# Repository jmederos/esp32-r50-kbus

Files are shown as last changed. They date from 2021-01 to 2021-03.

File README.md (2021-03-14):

# ESP32 K-bus Interface

[][license-url]
[][linkedin-url]

## Table of Contents

* [About the Project](#about)
  * [Hardware](#hardware)
  * [Software](#software)
* [Getting Started](#getting-started)
  * [Prerequisites](#prerequisites)
  * [Building](#building)
  * [Installing](#installing)
* [Roadmap](#roadmap)
* [License](#license)

## About

K-bus/I-bus to Bluetooth bridge for Mini/BMWs. Developed on esp-idf 4.0.2 and a 2006 Mini Cooper. Main goal was to get AVRCP control from steering wheel to iPhone; going forward looking to make it a platform for emulating K-bus devices.

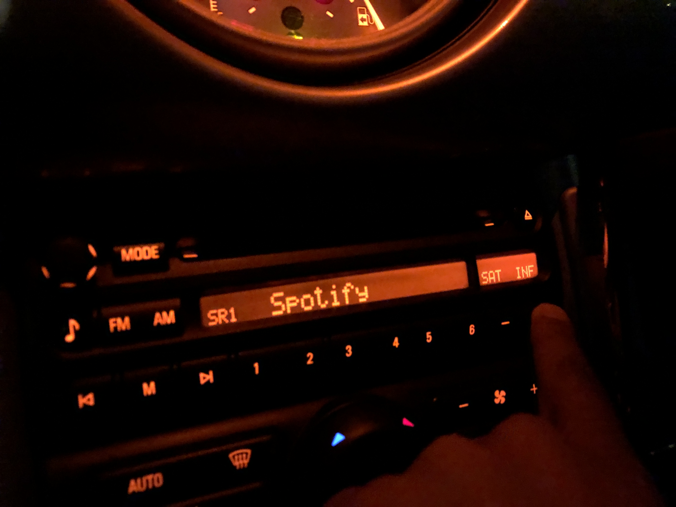
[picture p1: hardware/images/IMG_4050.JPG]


### Hardware

See [hardware](hardware) folder

### Software

* [esp-idf](https://github.com/espressif/esp-idf)
* [btstack](https://github.com/bluekitchen/btstack)

<!-- GETTING STARTED -->
## Getting Started

Clone, build, and flash.

### Prerequisites

Install `esp-idf` and the ESP32 `btstack` port by following the respective instructions.

### Building

#### Hardware

**TBD**

#### Software

* Clone this repo and its submodules `git clone --recursive https://github.com/jmederos/esp32-r50-kbus.git`
* After installing prequisites, run the helper script `./tools/build.sh` to compile
* `./tools/flash_monitor.sh` to load onto ESP32 and run `idf.py monitor`
_Note: Helper scripts in tools folder assume a WSL Ubuntu install w/ESP32 on Windows COM4_

### Installing

* Use OEM CD changer pre-wiring in R50 behind right side panel in trunk.

#### R50 Support Docs
* [How to find pre-wiring](https://www.northamericanmotoring.com/forums/navigation-and-audio/224408-can-t-find-cd-changer-pre-wiring.html)
* [CD changer installation instructions](https://new.minimania.com/images/instructions/OEM%20CD%20Changer.pdf)

## Roadmap
| Feature | Status | Notes |
| --- | --- | --- |
| Software POC: control phone via AVRCP w/o A2DP advertised. | 👌🏽 | _Although part of the BT spec, example implementations on AVRCP-only are hard to come by._ |
| Hardware POC: acquire + test k-line transceivers. | 🙌🏽 | |
| K-bus proof concept, pickup MFL messages. | 👍🏽 | _Works in vehicle, works in mockup w/Navcoder + iPhone streaming to a BT headphone amp._ |
| Write to radio head unit display | 🥳 | _Seems to work, now let's do scrolling display_ |
| SDRS Emulation | 👍🏽 | _Functional, didn't really like the fact that FiiO BT amp didn't shutdown with car; will stick to aux input + `TEL` display updates for now._ |
| Write to radio head unit display | 🥳 | _Seems to work, now let's do scrolling display_ |
| [AMS](https://developer.apple.com/library/archive/documentation/CoreBluetooth/Reference/AppleMediaService_Reference/Specification/Specification.html) instead of AVRCP | | _Didn't know this was a thing, seems like a better bet; btstack + esp-idf is a little clunky._ |
| [ANCS](https://developer.apple.com/library/archive/documentation/CoreBluetooth/Reference/AppleNotificationCenterServiceSpecification/Introduction/Introduction.html) Support & update radio display w/push notification | 🤞 | |

_See the [open issues](https://github.com/jmederos/esp32-r50-kbus/issues) for a list of proposed features (and known issues)._

## References
* [iPod ↔ Sirius IBus adapter](https://github.com/blalor/iPod_IBus_adapter) - _Referenced for SDRS packet logs (my car isn't equiped with one.)_
* [Hack The IBus](http://web.archive.org/web/20110320205413/http://ibus.stuge.se/Main_Page)

## License

Distributed under the MPL 2.0 License. See `LICENSE` for more information.

<!-- MARKDOWN LINKS & IMAGES -->
<!-- https://www.markdownguide.org/basic-syntax/#reference-style-links -->
[license-shield]: https://img.shields.io/badge/license-MPL%202.0-blue
[license-url]: https://github.com/jmederos/esp32-r50-kbus/blob/master/LICENSE
[linkedin-shield]: https://img.shields.io/badge/-LinkedIn-black.svg?style=flat-square&logo=linkedin&colorB=555
[linkedin-url]: https://linkedin.com/in/jacobmederos

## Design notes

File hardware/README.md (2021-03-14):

# Hardware

## Microcontroller
* [Sparkfun MicroMod ESP32](https://www.sparkfun.com/products/16781)
* [Sparkfun MicroMod ATP Board](https://www.sparkfun.com/products/16885)

## Power Regulation
| Part | Notes |
| --- | --- |
| ~~[On Semi NCV7805BTG 5V Regulator](https://www.digikey.com/en/products/detail/on-semiconductor/921437)~~ | Too inefficient
| [USB Power Supply](https://www.amazon.com/gp/product/B07KWRH61D) | Worked well for prototyping w/MicroMod ESP32
| [OKI-78SR-5](https://www.digikey.com/en/products/detail/OKI-78SR-5-1-5-W36H-C/3438675) | For v1 of feather board

## Transciever ICs
| Part | Status | Notes |
| --- | --- | --- |
| [ON Semi NCV7428D13R2G](https://www.digikey.com/en/products/detail/on-semiconductor/5022588) | 🤷🏽‍♂️ | Have it; still untested. |
| [NXP TJA1021T](https://www.digikey.com/en/products/detail/nxp-usa-inc/2034448) | 👍🏽 | Using with a `CP2102` USB ⇄ Serial to interface with NavCoder and simulate bus on desktop. |
| [TI SN65HVDA195QDRQ1](https://www.digikey.com/en/products/detail/texas-instruments/2094636) | 👎🏽 | Used on initial in-car perfboard prototypes. Works ok, but susceptible to glitching the bus (doors randomly unlocked); doesn't have tx timeout or contention detection. Best used to create a simulated bus as the controlling node like the `NXP` part above. |
| [Microchip MCP2025](https://www.digikey.com/en/products/detail/microchip-technology/3543134) | 🤷🏽‍♂️ | Have it; unlikely to test/use it. Doesn't have failsafe features and isn't pin-compatible w/`TI` |
| [Microchip MCP2004(A)](https://www.digikey.com/en/products/detail/MCP2004AT-E-SN/2803651) | 👍🏽 | Selected for tx timeout and bus contention detection + added bonus of `FAULT` pin. Also pin compatible with `TI` and `NXP` parts used for prototyping. So far, only tested `MCP2004A`; works in simulated bus setup. |
| [Microchip MCP2003B](https://www.digikey.com/en/products/detail/this-gets-ignored-🤷🏽‍♂️/5810590) | 🤷🏽‍♂️ | Selected for tx timeout and bus contention detection. Also pin compatible with `TI` and `NXP` parts used for prototyping. Have it; still untested. |

## Connector
The CD Changer connectors are a 3-pin power/data (all populated) and 6-pin audio (3 or 4 populated)
| Part | Notes |
| --- | --- |
| [TE AMP 1-1718346-1](https://www.newark.com/these/doNot/matter/dp/86Y2196) | Existing pre-wiring connector supplying `gnd`, `12v`, `kbus` |
| [TE AMP 1-968700-1](https://www.newark.com/these/doNot/matter/dp/86Y4923) | Matching socket for above; a row of 3 pin headers can also be used if this can't be sourced. OEM part [BMW 61 13 6 931 929](https://www.ecstuning.com/b-genuine-bmw-parts/pin-terminal/61136931929/) is order of magnitude more expensive. |
| [TE AMP 1379118-1](https://www.newark.com/these/doNot/matter/dp/69AH9772) | Matching socket for 6-pin audio connector. Depending on vehicle either 3 pin unbalanced audio or 4 pin balanced audio. |

## Board
Created a simple board for a more permanent installation

### BOM
_TODO_

### Pictures
<p>
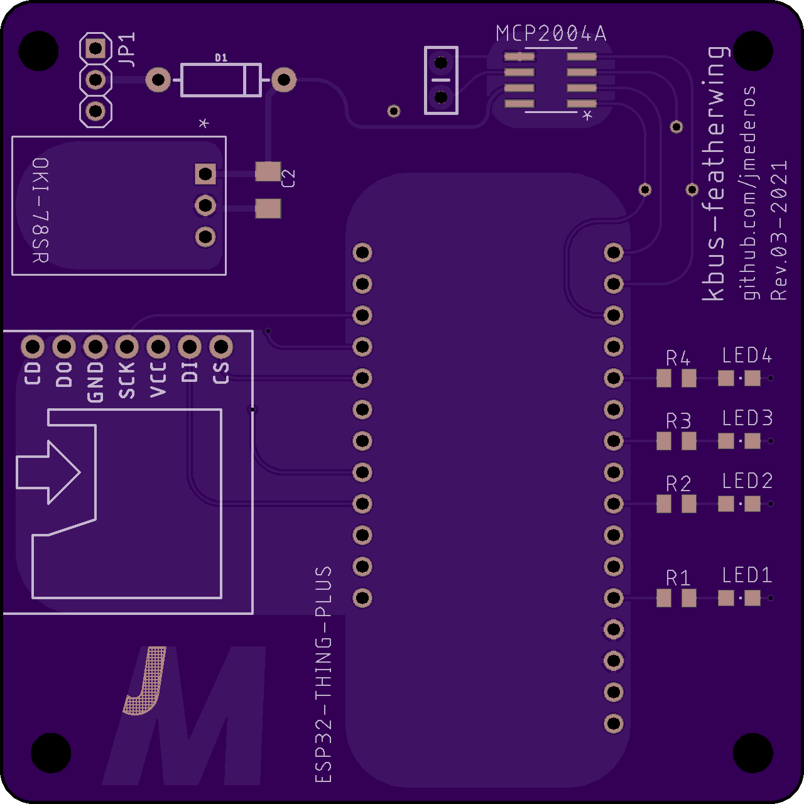
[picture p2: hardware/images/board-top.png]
  
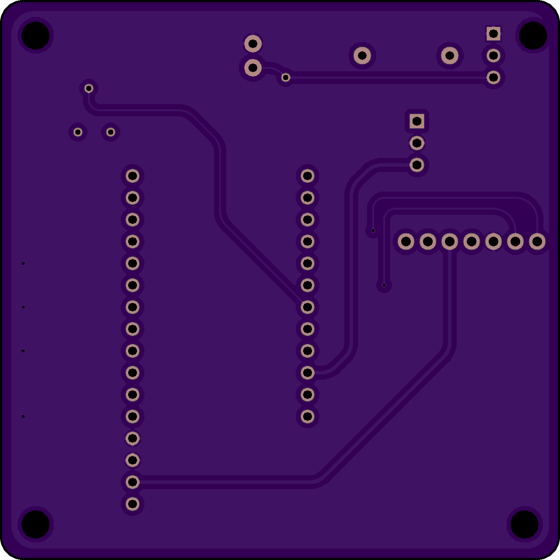
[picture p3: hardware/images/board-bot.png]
  
</p>
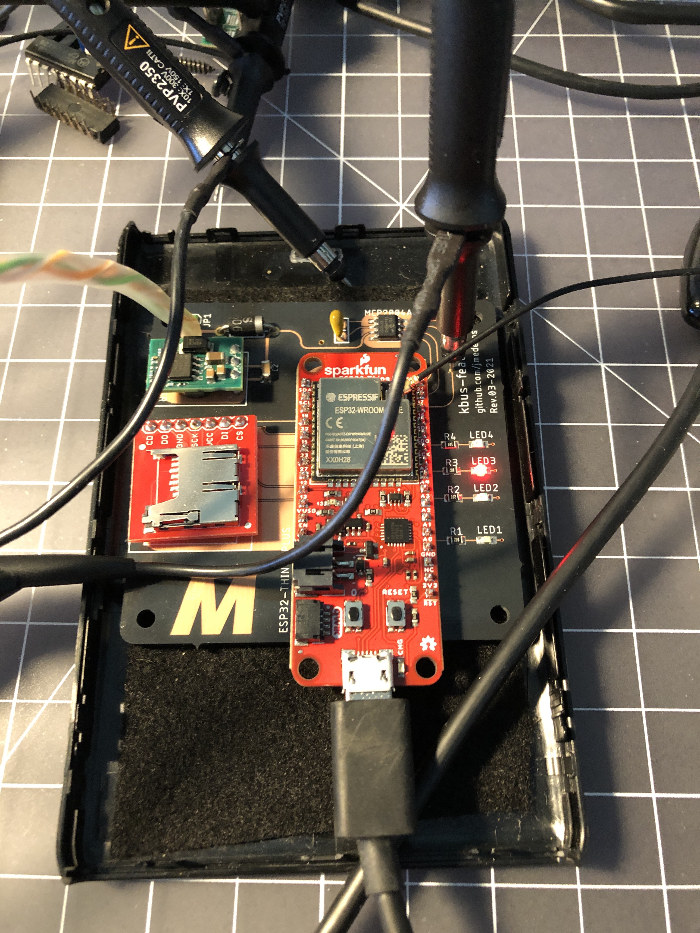
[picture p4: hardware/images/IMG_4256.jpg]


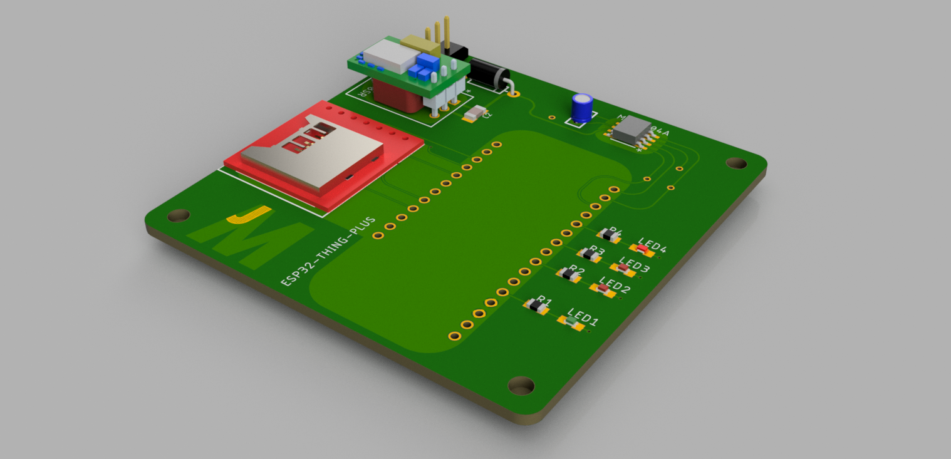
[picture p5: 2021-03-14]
hardware/images/thing-plus-carrier v12.PNG

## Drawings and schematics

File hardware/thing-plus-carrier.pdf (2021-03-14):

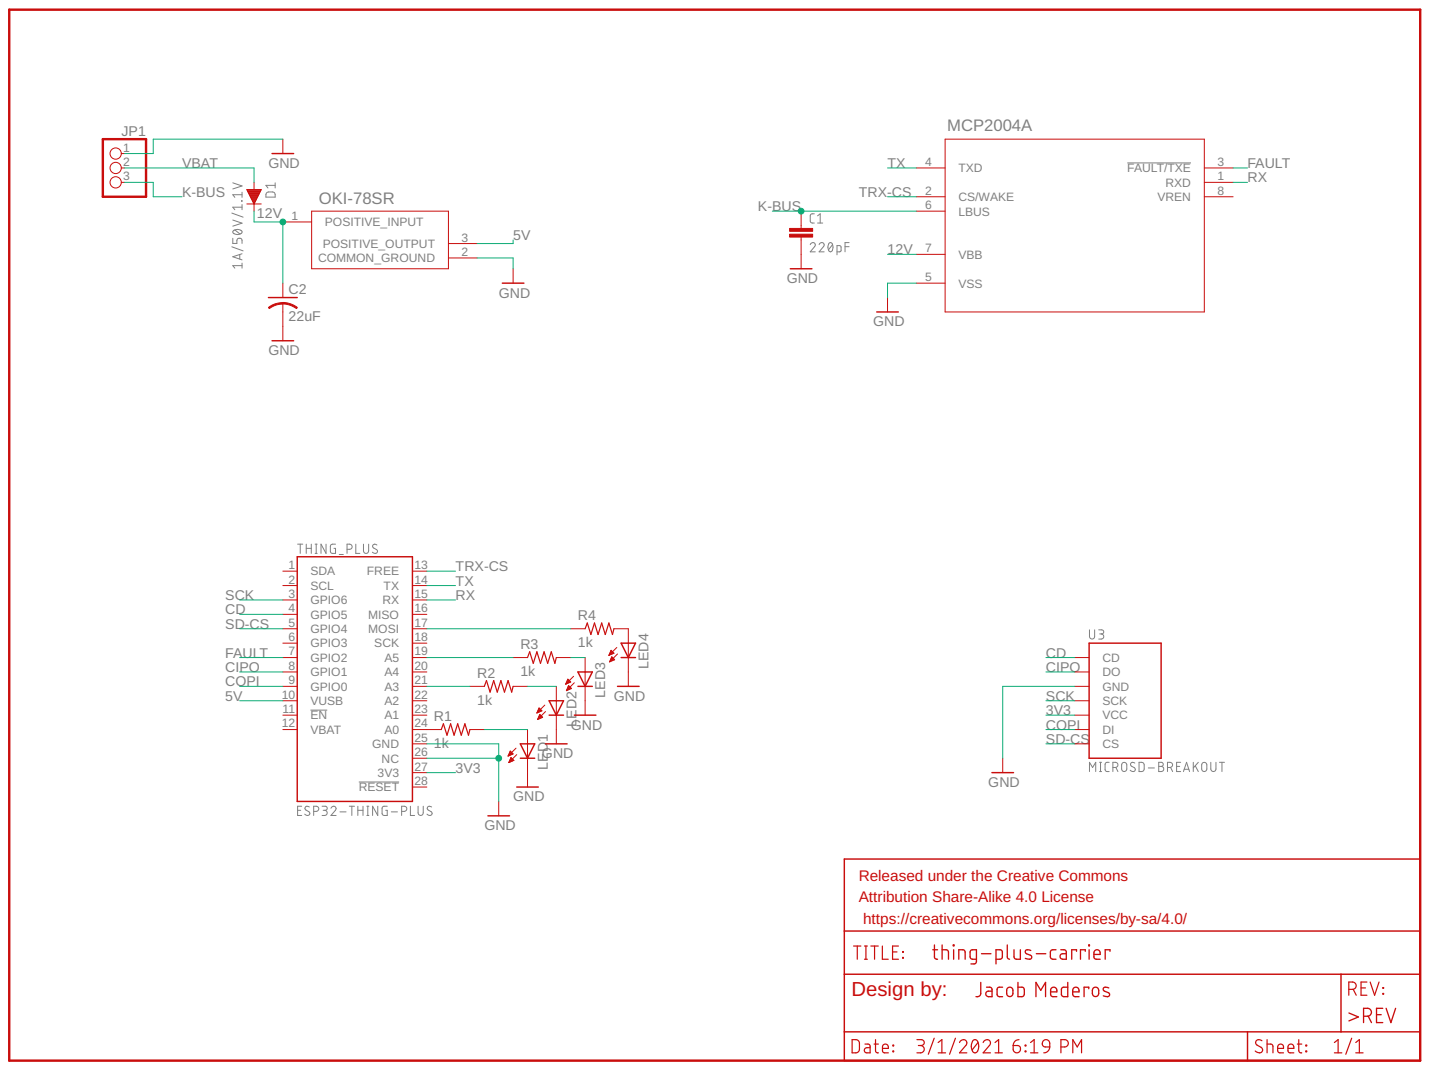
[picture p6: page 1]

Released under the Creative Commons Attribution Share-Alike 4.0 License

https://creativecommons.org/licenses/by-sa/4.0/

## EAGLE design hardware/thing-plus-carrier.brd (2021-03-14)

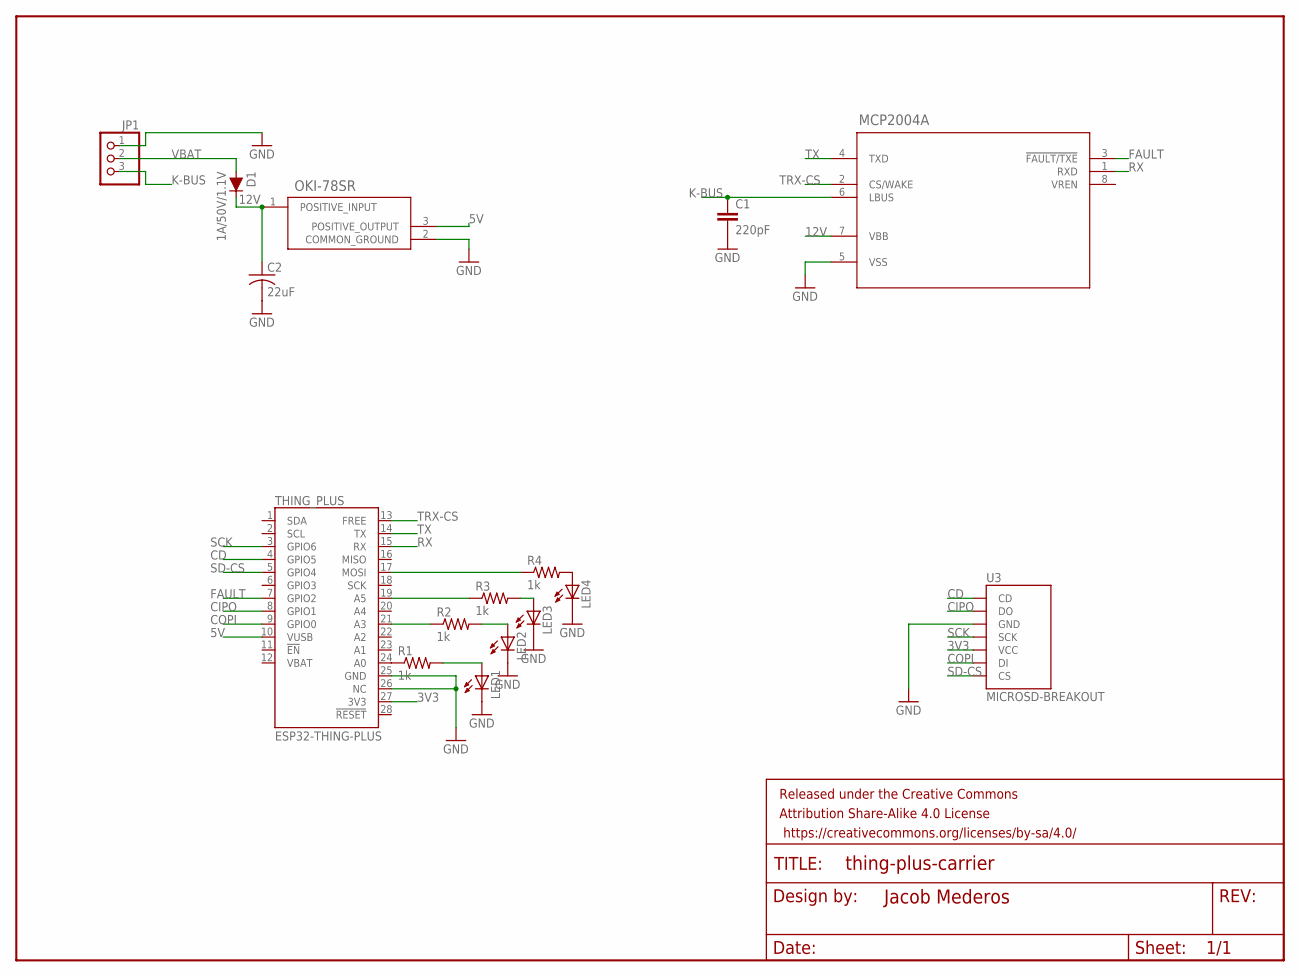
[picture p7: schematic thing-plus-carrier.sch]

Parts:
C1: 220pF; CAP-PTH-SMALL-KIT
C2: 22uF; C1206K
D1: 1A/50V/1.1V; DIODE-1N4001
ESP32-THING-PLUS: THING_PLUS
FRAME1: FRAME-LETTERNO_PACKAGE; DUMMY
JP1: PINHD-1X3; 1X03
LED1, LED2, LED3, LED4: LEDCHIPLED_0805; CHIPLED_0805
MCP2004A: MCP2004A-E/SNSOIC8_4P9X3P9MC_MCH-M; SOIC8_4P9X3P9MC_MCH-M
OKI-78SR: OKI-78SR-5/1.5-W36H-C; OKI-78SR-5/1.5-W36H-C_MUR
R1, R2, R3, R4: 1k; R0805
U3: MICROSD-BREAKOUT

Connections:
3V3: ESP32-THING-PLUS.27 (3V3), U3.VCC
5V: ESP32-THING-PLUS.10 (VUSB), OKI-78SR.3 (POSITIVE_OUTPUT)
12V: C2.1, D1.C, MCP2004A.7 (VBB), OKI-78SR.1 (POSITIVE_INPUT)
CD: ESP32-THING-PLUS.4 (GPIO5), U3.CD
CIPO: ESP32-THING-PLUS.8 (GPIO1), U3.DO
COPI: ESP32-THING-PLUS.9 (GPIO0), U3.DI
FAULT: ESP32-THING-PLUS.7 (GPIO2), MCP2004A.3 (!FAULT/TXE)
GND: C1.2, C2.2, ESP32-THING-PLUS.25 (GND), ESP32-THING-PLUS.26 (NC), JP1.1, LED1.C, LED2.C, LED3.C, LED4.C, MCP2004A.5 (VSS), OKI-78SR.2 (COMMON_GROUND), U3.GND
K-BUS: C1.1, JP1.3, MCP2004A.6 (LBUS)
unnamed: ESP32-THING-PLUS.19 (A5), R3.1
unnamed: ESP32-THING-PLUS.24 (A0), R1.1
unnamed: ESP32-THING-PLUS.21 (A3), R2.1
unnamed: ESP32-THING-PLUS.17 (MOSI), R4.1
unnamed: LED4.A, R4.2
unnamed: LED3.A, R3.2
unnamed: LED2.A, R2.2
unnamed: LED1.A, R1.2
RX: ESP32-THING-PLUS.15 (RX), MCP2004A.1 (RXD)
SCK: ESP32-THING-PLUS.3 (GPIO6), U3.SCK
SD-CS: ESP32-THING-PLUS.5 (GPIO4), U3.CS
TRX-CS: ESP32-THING-PLUS.13 (FREE), MCP2004A.2 (CS/WAKE)
TX: ESP32-THING-PLUS.14 (TX), MCP2004A.4 (TXD)
VBAT: D1.A, JP1.2

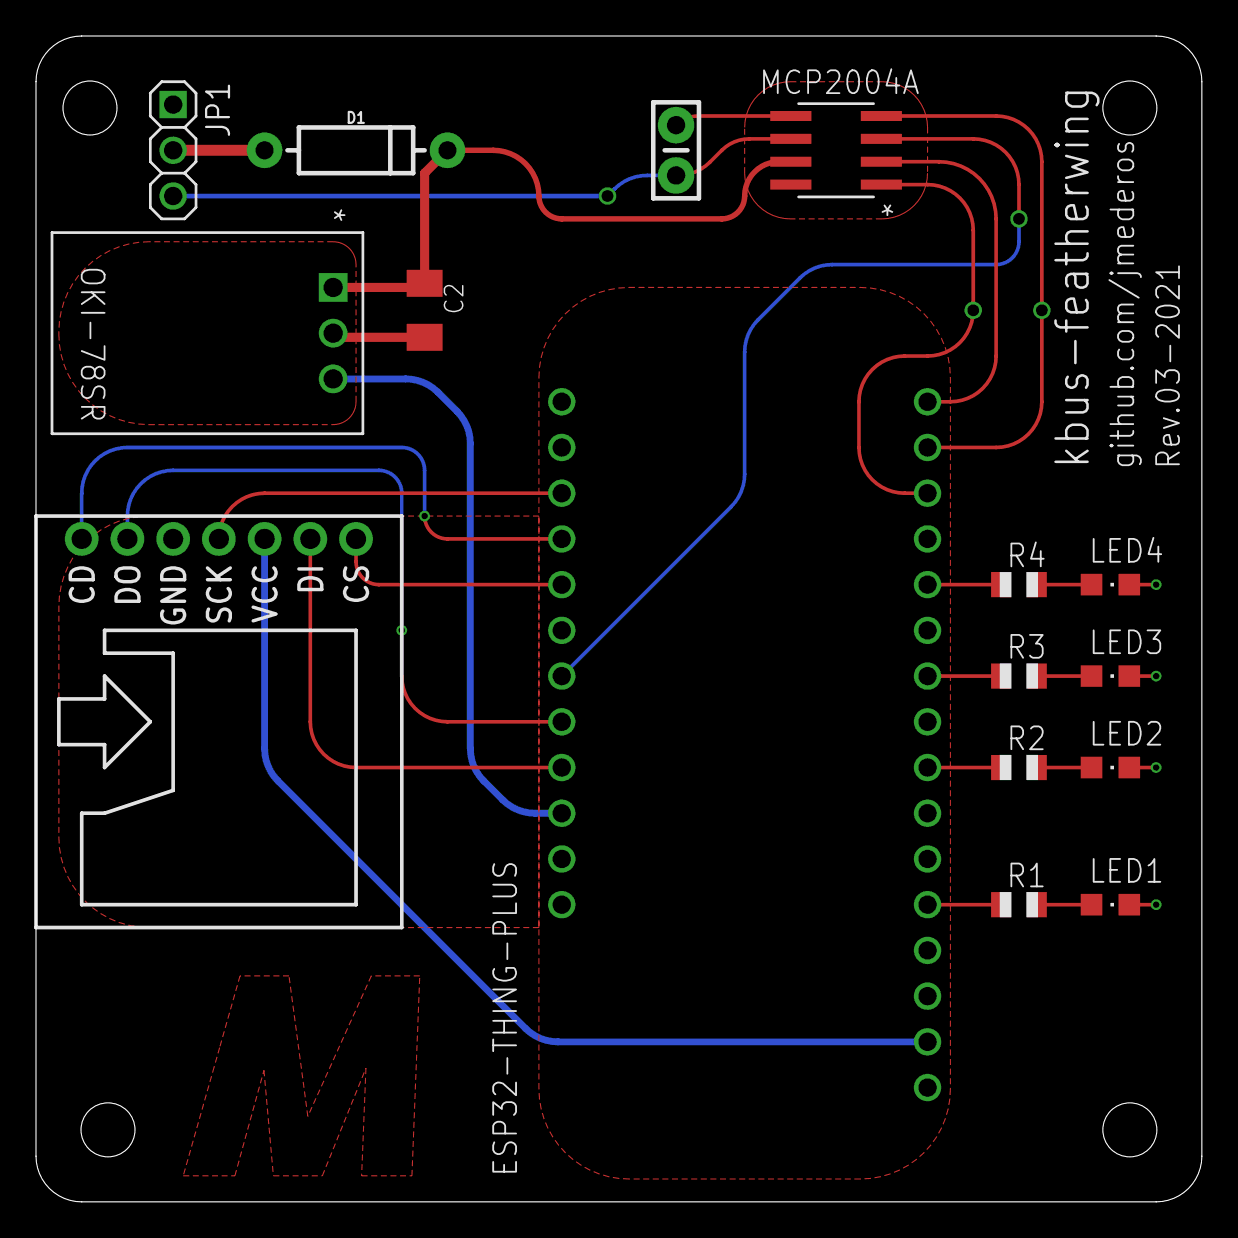
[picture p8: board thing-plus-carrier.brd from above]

Board: 2 copper layers, 64.8 x 64.8 mm, 17 parts (0 on the bottom side), 23 nets.

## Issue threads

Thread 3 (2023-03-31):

ninja: error: 'C:/Users/mhipik/Desktop/PROJEKT BMW/esp32-r50-kbus/html', needed by 'esp-idf/espfs/espfs_image.bin',

marttin-h, 2023-03-31:
hi, I get this error when I run the command idf.py -p COM6 flash
Executing "ninja flash"...
ninja: error: 'C:/Users/user01/Desktop/esp32-r50-kbus/html', needed by 'esp-idf/espfs/espfs_image.bin', missing and no known rule to make it
ninja failed with exit code 1, output of the command is in the ....

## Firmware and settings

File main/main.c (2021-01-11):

// C stdlib includes
#include <stddef.h>
#include <stdio.h>

// FreeRTOS includes
#include "freertos/FreeRTOS.h"
#include "freertos/projdefs.h"
#include "freertos/queue.h"
#include "freertos/task.h"

// esp-idf includes
#include "esp_system.h"
#include "esp_log.h"
#include "nvs_flash.h"

// btstack includes
#include "btstack_port_esp32.h"
#include "btstack_run_loop.h"
#include "hci_dump.h"

// component includes
#include "bt_services.h"
#include "wifi_service.h"
#include "kbus_service.h"
#include "bt_common.h"

#define SECONDS(sec) ((sec*1000) / portTICK_RATE_MS)

// TODO: Add these as menuconfig items
#define R50_BT_ENABLED
// #define R50_WIFI_ENABLED

// ! Debug Flags
// #define TASK_DEBUG

static const char* TAG = "r50-main";
static QueueHandle_t bt_cmd_queue, bt_info_queue;

#ifdef TASK_DEBUG
static void watcher_task(){
    const size_t bytes_per_task = 40;
    char *task_list_buffer = NULL;
    vTaskDelay(SECONDS(5));

    while(1){
        task_list_buffer = (char*) malloc(uxTaskGetNumberOfTasks() * bytes_per_task);
        if (task_list_buffer == NULL) {
            ESP_LOGE(TAG, "failed to allocate buffer for vTaskList output");
            abort();
        }

        vTaskList(task_list_buffer);
        printf("\n%sTask\t\tStat\tPrity\tHWM\tTsk#\tCPU%s\n", "\033[1m\033[4m\033[44;1m\033[K", LOG_RESET_COLOR);
        printf("%s", task_list_buffer);

        vTaskGetRunTimeStats(task_list_buffer);
        printf("%sTask\t\tAbs Time\t\tUsage%%%s\n", "\033[1m\033[4m\033[42m\033[K", LOG_RESET_COLOR);
        printf("%s", task_list_buffer);

        free(task_list_buffer);
        vTaskDelay(SECONDS(120));
    }
}

static void create_watcher_task(){
    int task_ret = xTaskCreate(watcher_task, "task_watcher", 4096, NULL, 5, NULL);
    if(task_ret != pdPASS){ESP_LOGE(TAG, "task_watcher creation failed with: %d", task_ret);}
}
#endif

static void initNVS(){
    //Initialize NVS
    esp_err_t ret = nvs_flash_init();
    if (ret == ESP_ERR_NVS_NO_FREE_PAGES || ret == ESP_ERR_NVS_NEW_VERSION_FOUND) {
      ESP_ERROR_CHECK(nvs_flash_erase());
      ret = nvs_flash_init();
    }
    ESP_ERROR_CHECK(ret);
}

int app_main(void){
    initNVS();

#ifdef TASK_DEBUG
    ESP_LOGI(TAG, "Creating Task Watcher");
    create_watcher_task();
#endif

    // Setup bluetooth command queue
    bt_cmd_queue = xQueueCreate(4, sizeof(bt_cmd_type_t));
    // Setup bluetooth "now playing" queue
    bt_info_queue = xQueueCreate(2, sizeof(bt_now_playing_info_t));

    // Setup kbus service; has side-effect of initializing and starting UART driver.
    init_kbus_service(bt_cmd_queue, bt_info_queue);

#ifdef R50_WIFI_ENABLED // Gating wifi and bt since there's still issues with them running concurrently.
    wifi_init_softap();
#endif

#ifdef R50_BT_ENABLED
    ESP_LOGI(TAG, "Starting bt services...");
    bluetooth_services_setup(bt_cmd_queue, bt_info_queue);
    // Running btstack_run_loop_execute() as it's own task or in a wrapper wasn't working;
    // however, does work as lowest priority loop after other tasks. Going with this.
    ESP_LOGI(TAG, "btstack run loop");
    btstack_run_loop_execute();
#else
    while(1) {
        printf("Bluetooth runloop goes here...\n");
        vTaskDelay(600000 / portTICK_PERIOD_MS);
    }
#endif

    return 0;
}

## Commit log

2020-11-07 Initial commit 🎉🥳
2020-12-08 WIP—Refactored bt component; added server task stub; added simple build scripts
2020-12-09 WIP—Added wifi AP component. btstack + wifi not coexisting properly
2020-12-10 WIP—UART Driver component, configured ESP32 for multicore FreeRTOS
2020-12-11 Readme updates, UART tested working with USB adapter and terminal
2020-12-14 Added kbus service component. 'Device Status Ready' message shows up on NavCoder🎉
2020-12-14 Added kbus message encoder, removed KBUS_TX_TEST_IS_ENABLED code, added #defines for kbus addresses
2020-12-16 Refactor kbus driver & service to use queues
2020-12-16 Basic AVRCP working w/NavCoder and iPhone 🥳
2020-12-21 Refactored uart tx from function call to queue
2020-12-29 Added ENABLE Pin to uart driver, updated CDC emulation, changed logging verbosity, removed broadcast message handling
2020-12-29 General implementation for sending Device Status Ready packets
2020-12-31 Debugging stuck messages... Seems ESP-IDF rx fifo doesn't flush into queue
    [main.c]
2020-12-31 Refactored UART RX code, solved panic & timing issue
    [main.c]
2021-01-03 UART driver documentation
2021-01-04 UART driver improvements: drop large messages, filter by command bitmask
2021-01-04 sdrs emulator as standalone component running on seperate task (works! 🥳). Fixed UART driver accidentally masking MFL commands
2021-01-11 AVRCP Track info pretty much working; need to implement long text scrolling
2021-02-11 starting on featherwing board
    [thing-plus-carrier.brd, thing-plus-carrier.sch]
2021-02-28 laying out featherwing schematic
    [thing-plus-carrier.brd, thing-plus-carrier.sch]
2021-03-02 Finished rev.1 board []~(￣▽￣)~* ; Updated docs
    [thing-plus-carrier.brd, thing-plus-carrier.sch]
2021-03-14 board images

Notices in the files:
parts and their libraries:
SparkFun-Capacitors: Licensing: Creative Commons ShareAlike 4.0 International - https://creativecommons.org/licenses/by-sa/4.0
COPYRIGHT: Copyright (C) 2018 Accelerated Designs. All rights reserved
